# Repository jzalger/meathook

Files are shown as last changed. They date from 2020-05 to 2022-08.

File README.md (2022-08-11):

# Meat Hook







Meat Hook is a temperature and humidity controlled fridge for dry aging meat.
This project goes through designing the circuit and PCB as well as the surrounding full-stack web application and data
logging utilities. It also explores using various control algorithms including basic, PID, and machine learning approaches.

The controller is based on the [Particle Photon](http://www.particle.io), a Wifi enabled ARM based processor with a cloud-based API.
The web application backend is written in Python using the Flask framework. The frontend uses HTML and Javascript, leveraging the Bootstrap framework.

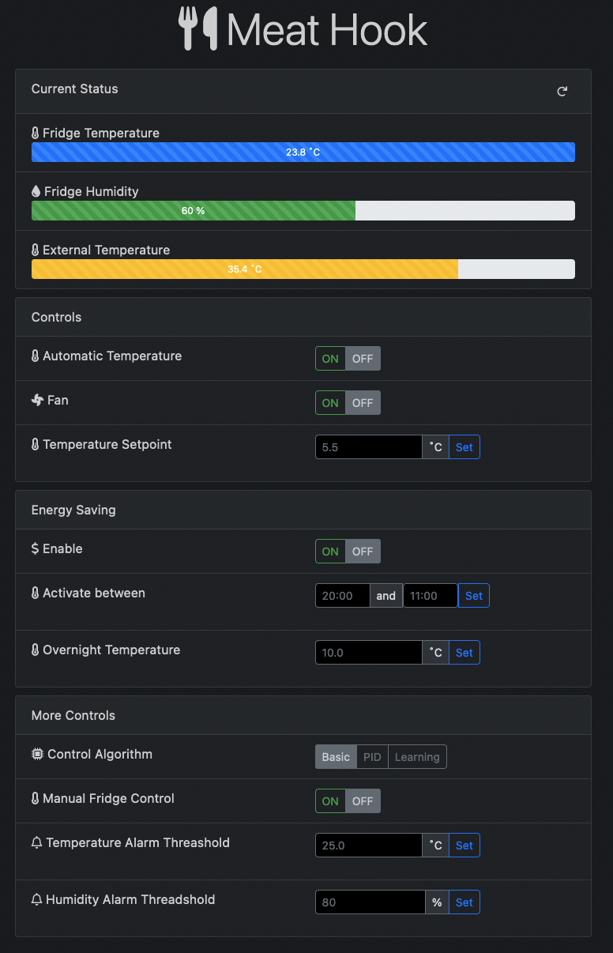
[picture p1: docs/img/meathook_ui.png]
User Interface


## Circuit and PCB Design

Below is a simple block diagram showing the sensors and actuators in the fridge.

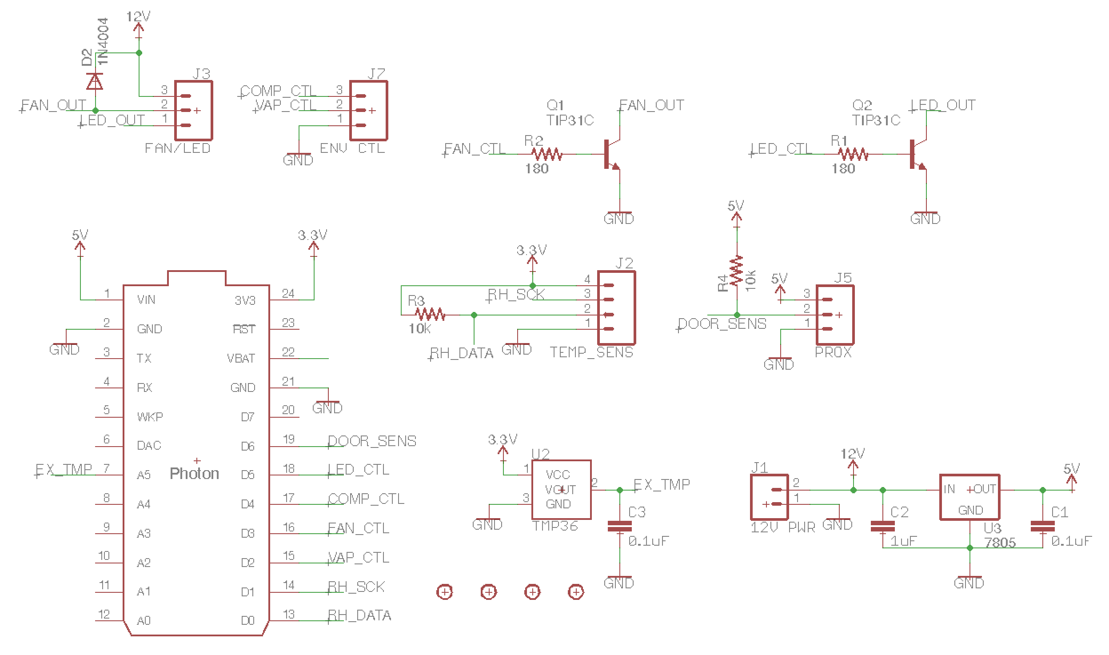
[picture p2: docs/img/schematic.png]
Schematic


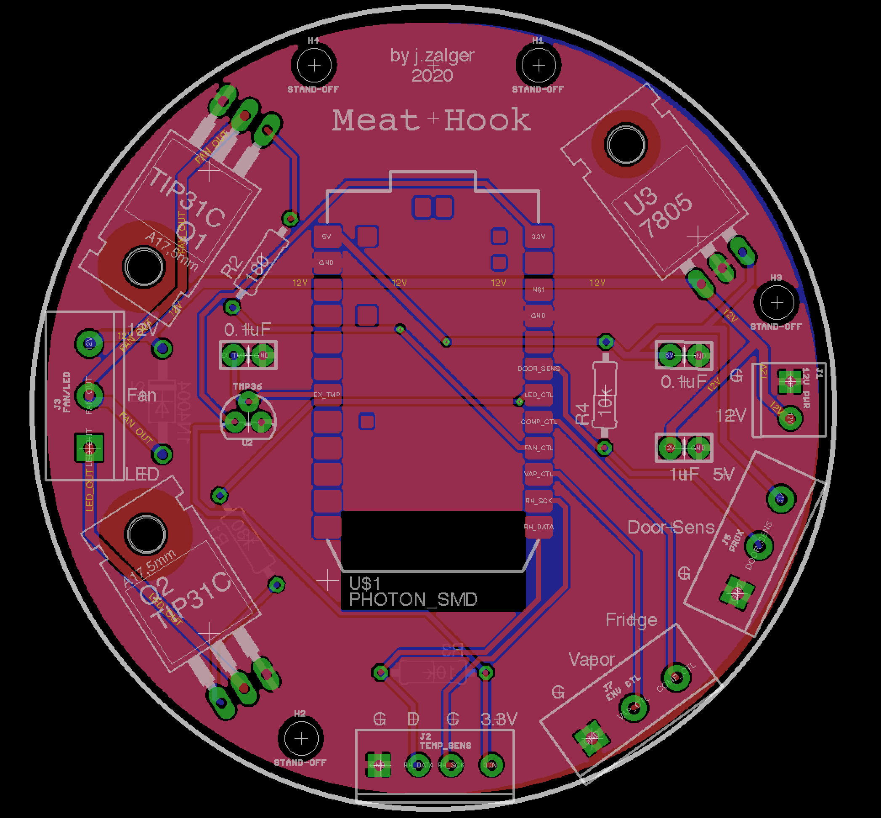
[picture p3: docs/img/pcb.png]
PCB


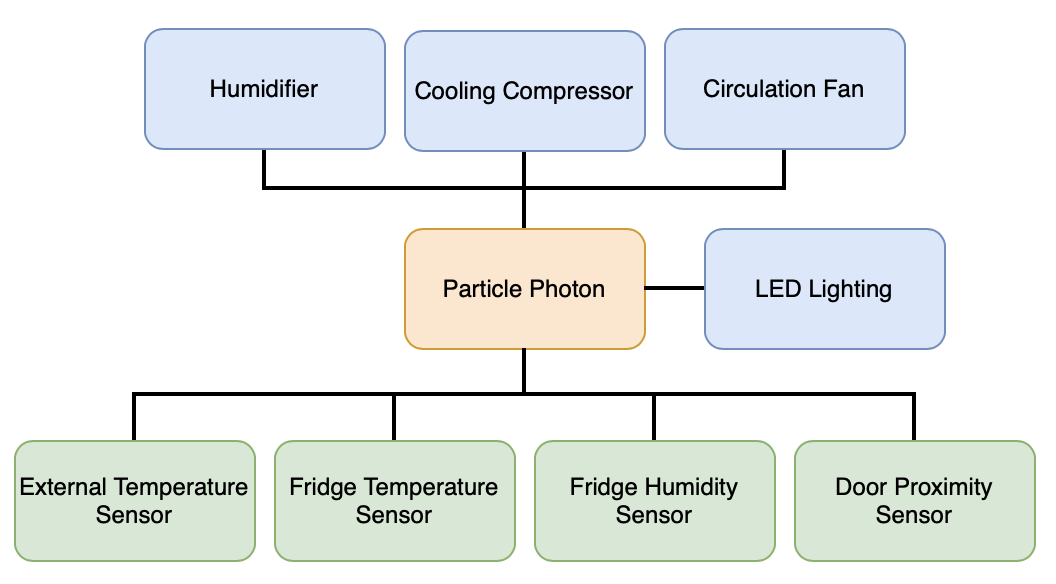
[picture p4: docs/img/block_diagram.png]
Block Diagram


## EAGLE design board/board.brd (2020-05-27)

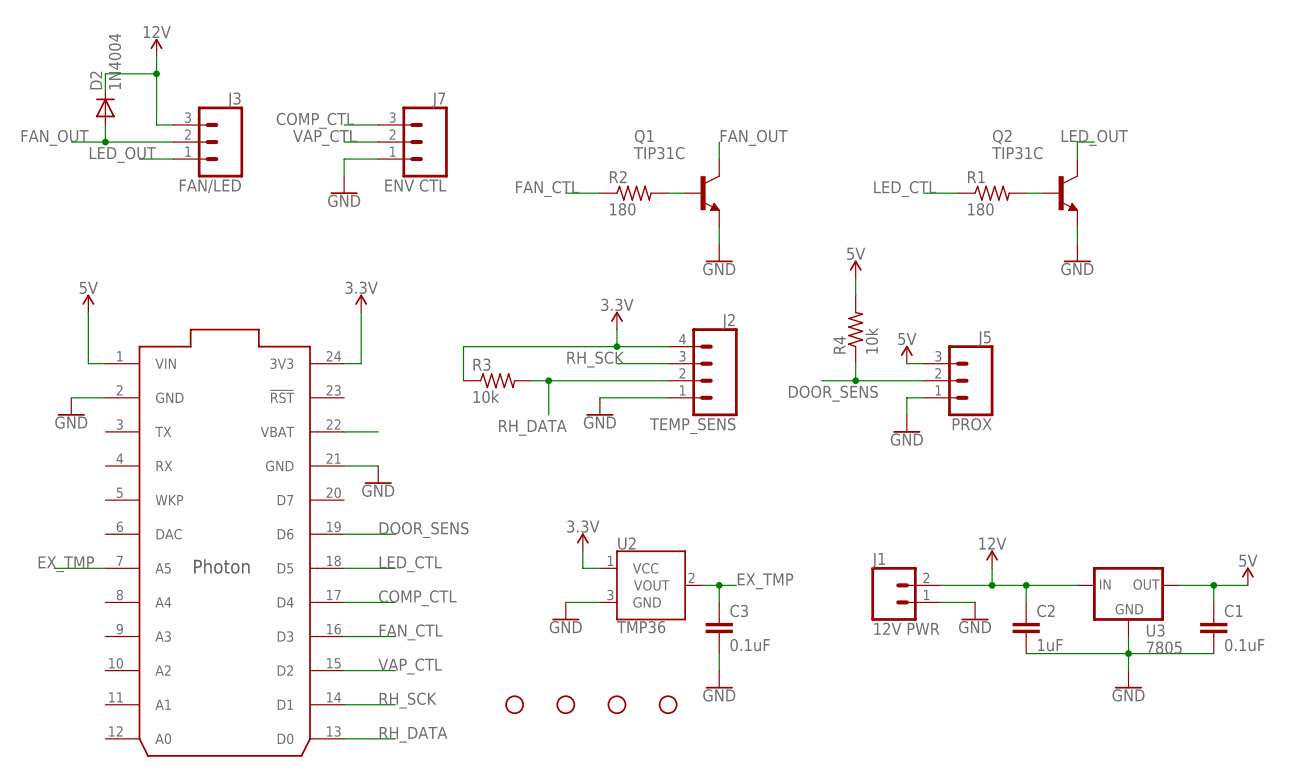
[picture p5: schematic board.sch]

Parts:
C1, C3: 0.1uF; CAP-PTH-SMALL-KIT
C2: 1uF; CAP-PTH-SMALL-KIT
D2: 1N4004; DO41-10
H1, H2, H3, H4: STAND-OFF
J1: 12V PWR; SCREWTERMINAL-3.5MM-2
J2: TEMP_SENS; SCREWTERMINAL-3.5MM-4_LOCK
J3: FAN/LED; SCREWTERMINAL-5MM-3
J5: PROX; SCREWTERMINAL-5MM-3
J7: ENV CTL; SCREWTERMINAL-5MM-3
Q1, Q2: TIP31C; TO220
R1, R2: 180; 0207/10
R3, R4: 10k; 0207/10
U2: TMP36; TO-92
U3: 7805; TO-220-ALT
U$1: PHOTON_SMD

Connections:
3.3V: J2.4, R3.1, U2.1 (VCC), U$1.24 (3V3)
5V: C1.1, J5.3, R4.2, U3.OUT, U$1.1 (VIN)
12V: C2.1, D2.C, J1.2, J3.3, U3.IN
COMP_CTL: J7.3, U$1.17 (D4)
DOOR_SENS: J5.2, R4.1, U$1.19 (D6)
EX_TMP: C3.1, U2.2 (VOUT), U$1.7 (A5)
FAN_CTL: R2.1, U$1.16 (D3)
FAN_OUT: D2.A, J3.2, Q1.2 (C)
GND: C1.2, C2.2, C3.2, J1.1, J2.1, J5.1, J7.1, Q1.3 (E), Q2.3 (E), U2.3 (GND), U3.GND, U$1.2 (GND), U$1.21 (GND)
LED_CTL: R1.1, U$1.18 (D5)
LED_OUT: J3.1, Q2.2 (C)
unnamed: Q2.1 (B), R1.2
unnamed: Q1.1 (B), R2.2
RH_DATA: J2.2, R3.2, U$1.13 (D0)
RH_SCK: J2.3, U$1.14 (D1)
VAP_CTL: J7.2, U$1.15 (D2)

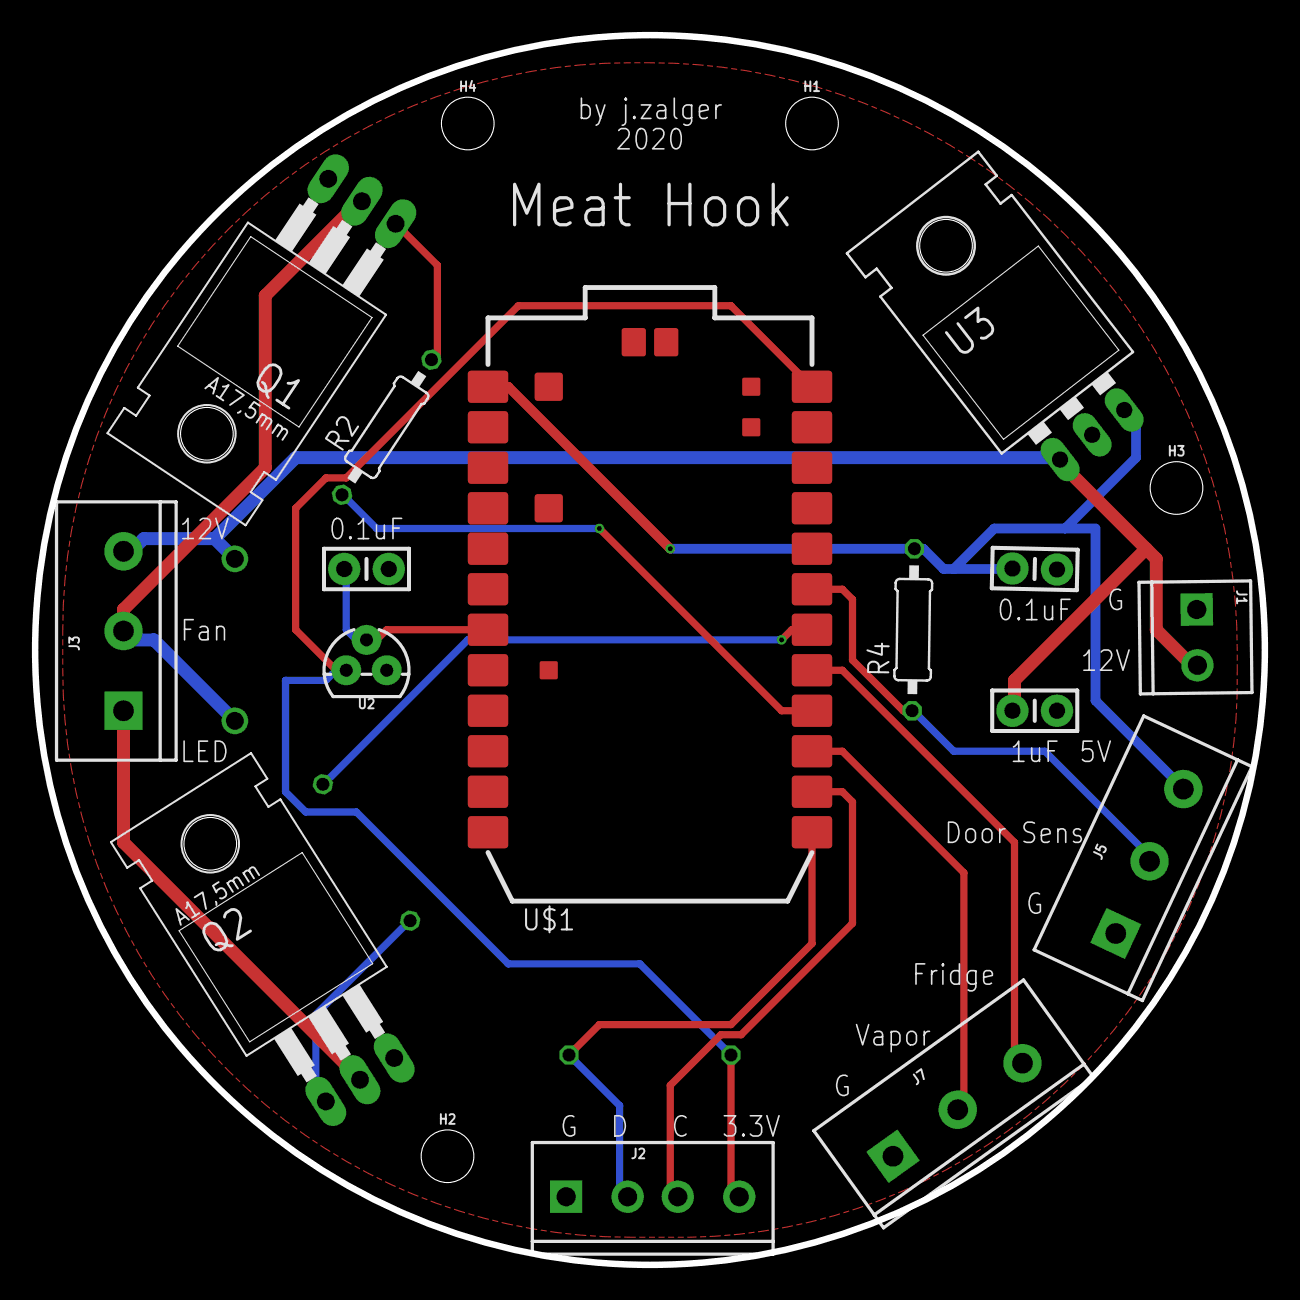
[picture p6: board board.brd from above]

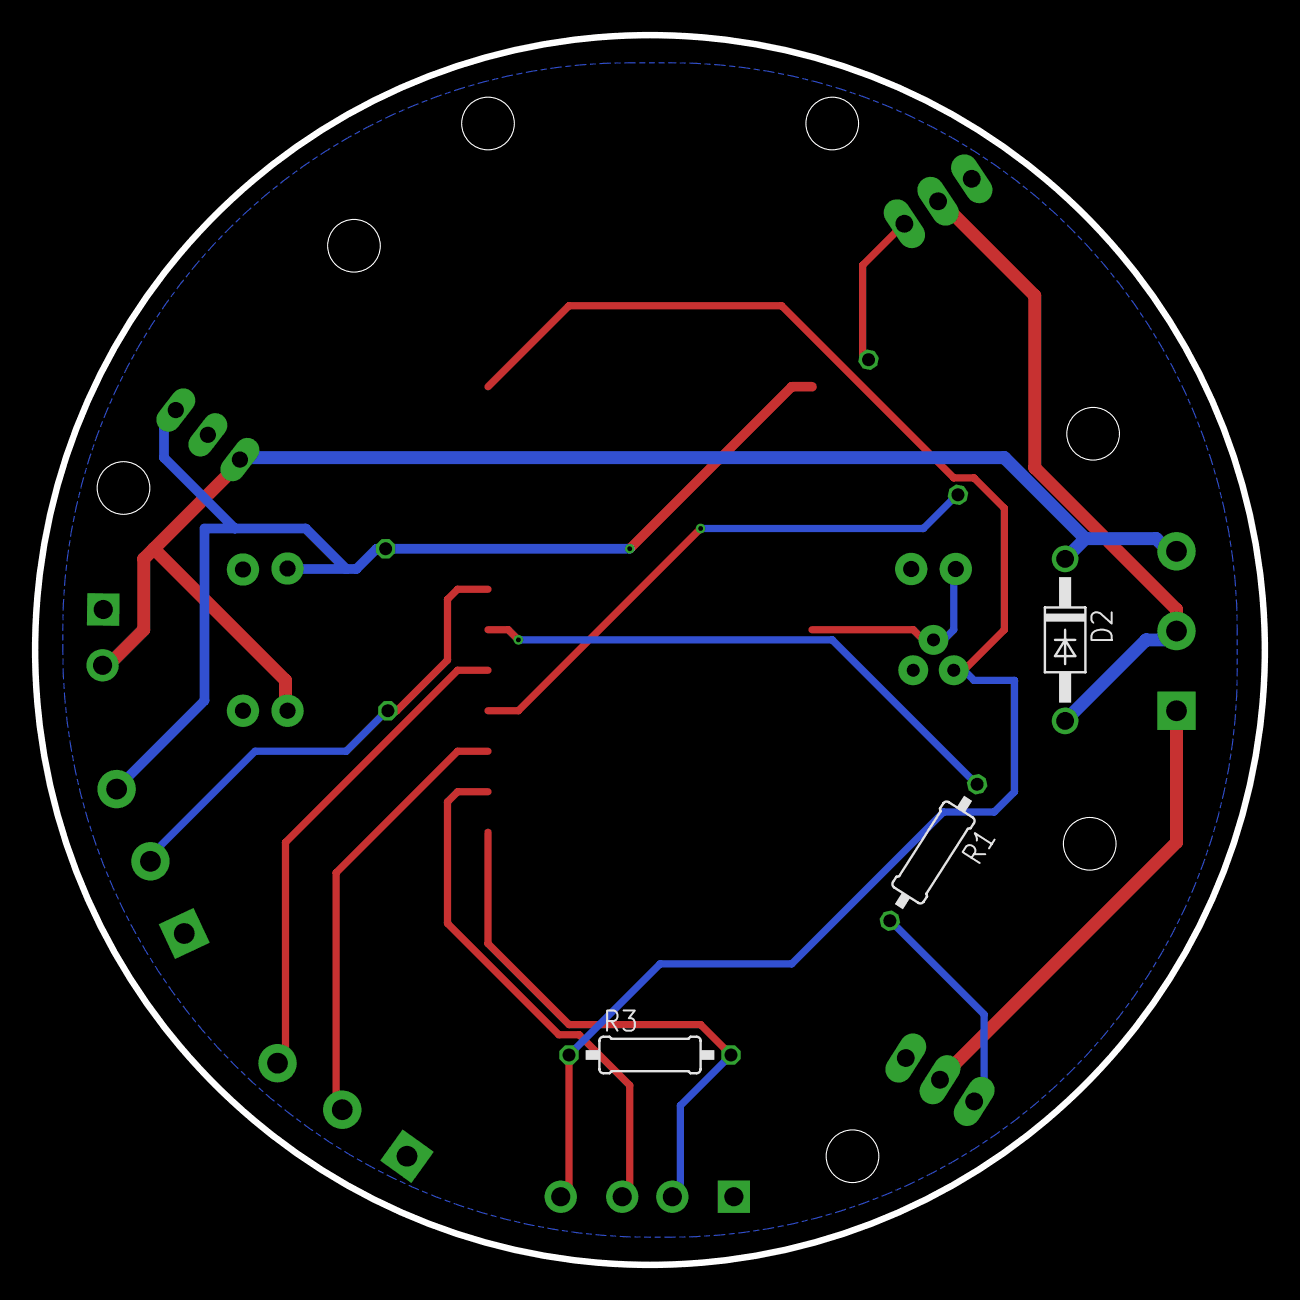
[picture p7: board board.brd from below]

Board: 2 copper layers, 77.1 x 77.1 mm, 22 parts (3 on the bottom side), 16 nets.

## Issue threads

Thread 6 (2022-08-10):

Persist state to device flash and recover to it on reboot

jzalger, 2022-08-10:

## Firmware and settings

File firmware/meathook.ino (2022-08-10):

// MeatHook
// J. Zalger - 2022
SYSTEM_THREAD(ENABLED);
#include <SHT1x.h>
#include <pid.h>
#include <string>
#include "basic_control.h"

#define REF_VOLTAGE 3.4  //Voltage reference for external temp sensor
#define SHT_SCK D1
#define SHT_DATA D0
#define FAN_PIN D3
#define FRIDGE_PIN D4
#define LED_PIN D5
#define DOOR_SENS D6
#define EXT_TEMP_PIN A5

double external_temp = 0.0;
double fridge_temp = 0.0;
double fridge_rh = 0.0;

// Parameters for PID control
double temp_setpoint = 5.5;
double current_temp_setpoint = temp_setpoint;
double es_temp_setpoint = temp_setpoint;
double temp_pid_output = 0.0;
int pid_temp_window_size = 60000;   // Time in milliseconds
unsigned long pid_temp_window_start_time;

int compressor_protect_time = 300;  // Time in seconds
int last_fridge_action = -compressor_protect_time * 1000;

double temp_alarm_delta = 15.0;  //+- deg C from setpoint to trigger alarm
double rh_alarm_limit = 50.0;    //Upper Rh limit to trigger alarm

bool temp_control = TRUE;
bool fan_state = TRUE;
bool fridge_state = FALSE;
bool temp_alarm = FALSE;
bool rh_alarm = FALSE;
bool stream_data = TRUE;
bool door_state = FALSE;  // False = CLOSED
bool logging_mode = TRUE;
bool led_state = FALSE;
bool es_state = FALSE;

struct ESTime {
    int hour = 0;  //Hours in 24 hr time 0-23
    int minutes = 0;  // Minutes in hour 0-59
    };

String es_start_string = "22:00";
String es_stop_string = "10:00";
ESTime es_start_time;
ESTime es_stop_time;

String state = "";

int stream_interval = 1; // Stream update interval in minutes
unsigned long last_stream_update;
unsigned long last_alarm_message;

SHT1x fridge_sensor(SHT_DATA, SHT_SCK);

String control_algorithm = "basic";

// Note: These PID settings here are arbitrary
PID temp_pid(&fridge_temp, &temp_pid_output, &current_temp_setpoint, 2.0, 2.0, 1.0, PID::P_ON_M, PID::DIRECT);

// Basic Control for temperature
BasicControl basic_temp_control(&fridge_temp, &current_temp_setpoint);

void setup() {
    pinMode(FRIDGE_PIN, OUTPUT);
    pinMode(FAN_PIN, OUTPUT);
    pinMode(LED_PIN, OUTPUT);

    Particle.variable("fridge_state", fridge_state);
    Particle.variable("external_temp", external_temp);
    Particle.variable("fridge_temp", fridge_temp);
    Particle.variable("fridge_rh", fridge_rh);
    Particle.variable("temp_setpoint", temp_setpoint);
    Particle.variable("current_temp_setpoint", current_temp_setpoint);
    Particle.variable("temp_control", temp_control);
    Particle.variable("fan_state", fan_state);
    Particle.variable("temp_alarm", temp_alarm);
    Particle.variable("rh_alarm", rh_alarm);
    Particle.variable("temp_alarm_delta", temp_alarm_delta);
    Particle.variable("rh_alarm_limit", rh_alarm_limit);
    Particle.variable("control_algorithm", control_algorithm);
    Particle.variable("led_state", led_state);
    Particle.variable("door_state", door_state);
    Particle.variable("es_state", es_state);
    Particle.variable("es_temp_setpoint", es_temp_setpoint);
    Particle.variable("es_start", es_start_string);
    Particle.variable("es_stop", es_stop_string);

    Particle.function("set_temp_setpoint", set_temp_setpoint);
    Particle.function("set_control", set_control);
    Particle.function("set_temp_control", set_temp_control);
    Particle.function("set_stream_data", set_stream_data);
    Particle.function("set_stream_interval", set_stream_interval);
    Particle.function("set_temp_alarm_delta", set_temp_alarm_delta);
    Particle.function("set_rh_alarm_limit", set_rh_alarm_limit);
    Particle.function("set_fan_state", set_fan_state);
    Particle.function("set_fridge_state", set_fridge_state);
    Particle.function("set_control_algorithm", set_control_algorithm);
    Particle.function("set_led_state", set_led_state);
    Particle.function("es_state", set_es_state);
    Particle.function("es_temp_setpoint", set_es_temp_setpoint);
    Particle.function("es_start", set_es_start_string);
    Particle.function("es_stop", set_es_stop_string);

    if (control_algorithm == "pid"){
        temp_pid.SetOutputLimits(0, pid_temp_window_size);
        temp_pid.SetMode(PID::AUTOMATIC);
    }
}

void loop() {
    delay(1000); // Dont overdrive the system

    // Turn on lights if door opens
    manage_light();

    external_temp = (((analogRead(EXT_TEMP_PIN) * REF_VOLTAGE) / 4095.0) - 0.5) * 100;
    fridge_temp = fridge_sensor.readTemperatureC();
    fridge_rh = fridge_sensor.readHumidity();

    // Account for energy saving
    if (es_state == TRUE){
        if (Time.hour() <= es_start_time.hour && Time.minute() <= es_start_time.minutes &&
            Time.hour() >= es_stop_time.hour && Time.minute() >= es_stop_time.minutes) {
                //Outside the ES Window
                current_temp_setpoint = temp_setpoint;
        } else {
            current_temp_setpoint = es_temp_setpoint;
        }
    } else {
        current_temp_setpoint = temp_setpoint;
    }

    if (temp_control == TRUE) {
        adjust_control();
    }

    if (fan_state == TRUE) {
        start_fan();
    } else {
        stop_fan();
    }

    handle_alarms();

    // Post readings to the cloud server
    if (stream_data == TRUE) {
        if ((millis() - last_stream_update) / 1000 > (stream_interval * 60)) {
            publish_state();
        }
    }
}


//##########################################################################################

void adjust_control(){
    if (control_algorithm == "pid"){
        temp_pid.Compute();
        unsigned long now = millis();
        if (now - pid_temp_window_start_time > pid_temp_window_size) {
            pid_temp_window_start_time += pid_temp_window_size;
        }
        if (temp_pid_output > now - pid_temp_window_start_time){
            start_fridge();
        } else {
            stop_fridge();
        }

    } else if (control_algorithm == "basic"){
        bool action = basic_temp_control.compute_action();
        if (action == TRUE){
            start_fridge();
        } else {
            stop_fridge();
        }
    }
}

void handle_alarms(){
    if (fridge_temp > temp_setpoint + temp_alarm_delta ||
            fridge_temp < temp_setpoint - temp_alarm_delta) {
                temp_alarm = TRUE;
    } else {
        temp_alarm = FALSE;
    }
    if (fridge_rh > rh_alarm_limit) {
        rh_alarm = TRUE;
    } else {
        rh_alarm = FALSE;
    }
}

void publish_state() {
    state = "fridge_temp=" + String(fridge_temp) + "," +
            "fridge_rh=" + String(fridge_rh) + "," +
            "external_temp=" + String(external_temp) + "," +
            "fridge_state=" + String::format("%s", fridge_state ? "True" : "False")  + "," +
            "fan_state=" + String::format("%s", fan_state ? "True" : "False") + "," +
            "door_state=" + String::format("%s", door_state ? "True" : "False") + "," +
            "temp_setpoint=" + String(temp_setpoint) + "," +
            "temp_alarm=" + String::format("%s", temp_alarm ? "True" : "False") + "," +
            "rh_alarm=" + String::format("%s", rh_alarm ? "True" : "False") + "," +
            "control_algorithm=" + control_algorithm + "," +
            "temp_alarm_delta=" + String(temp_alarm_delta) + "," +
            "rh_alarm_limit=" + String(rh_alarm_limit) + "," +
            "temp_control=" + String(temp_control ? "True" : "False") + "," +
            "es_state=" + String::format("%s", es_state ? "True" : "False") + "," +
            "es_temp_setpoint=" + String(es_temp_setpoint) + "," +
            "es_start=" + String(es_start_string) + "," +
            "es_stop=" + String(es_stop_string) + "," +
            "current_temp_setpoint=" + String(current_temp_setpoint);

    Particle.publish("state", state);
    last_stream_update = millis();
}

void start_fridge(){
    int time_since_last_action = millis() - last_fridge_action;
    if (time_since_last_action >= compressor_protect_time * 1000){
        digitalWrite(FRIDGE_PIN, HIGH);
        fridge_state = TRUE;
    }
}

void stop_fridge(){
    digitalWrite(FRIDGE_PIN, LOW);
    if (fridge_state == TRUE) {
        last_fridge_action = millis();
    }
    fridge_state = FALSE;
}


void start_fan(){
    digitalWrite(FAN_PIN, HIGH);
    fan_state = TRUE;
}

void stop_fan(){
    digitalWrite(FAN_PIN, LOW);
    fan_state = FALSE;
}

void manage_light(){
    door_state = digitalRead(DOOR_SENS);
    if (door_state == TRUE or led_state == TRUE){
        digitalWrite(LED_PIN, HIGH);
    } else {
        digitalWrite(LED_PIN, LOW);
    }
}

int set_temp_setpoint(String arg){
    temp_setpoint = arg.toFloat();
    return 0;
}

int set_control(String arg){
    if (arg == "ON") {
        temp_control = TRUE;
        return 0;
    } else if (arg == "OFF"){
        temp_control = FALSE;
        return 0;
    } else {
        return -1;
    }
}
int set_temp_control(String arg){
    if (arg == "ON") {
        temp_control = TRUE;
        return 0;
    } else if (arg == "OFF"){
        temp_control = FALSE;
        return 0;
    } else {
        return -1;
    }
}

int set_fridge_state(String arg){
    if (arg == "ON") {
        start_fridge();
        return 0;
    } else if (arg == "OFF"){
        stop_fridge();
        return 0;
    } else {
        return -1;
    }
}

int set_stream_data(String arg){
    if (arg == "ON"){
        stream_data = TRUE;
        return 0;
    } else if (arg == "OFF"){
        stream_data = FALSE;
        return 0;
    } else {
        return -1;
    }
}
int set_stream_interval(String arg){
    stream_interval = arg.toInt();
    return 0;
}
int set_temp_alarm_delta(String arg){
    temp_alarm_delta = arg.toFloat();
    return 0;
}
int set_rh_alarm_limit(String arg){
    rh_alarm_limit = arg.toFloat();
    return 0;
}
int set_fan_state(String arg){
    if (arg == "ON") {
        start_fan();
        return 0;
    } else if (arg == "OFF") {
        stop_fan();
        return 0;
    } else {
        return -1;
    }
}
int set_led_state(String arg){
    if (arg == "ON") {
        led_state = TRUE;
        return 0;
    } else if (arg == "OFF") {
        led_state = FALSE;
        return 0;
    } else {
        return -1;
    }
}
int set_control_algorithm(String arg){
    if (arg == "basic"){
        control_algorithm = "basic";
        return 0;
    } else if (arg == "pid") {
        control_algorithm = "pid";
        return 0;
    } else {
        return -1;
    }
}
int set_es_state(String arg){
    if (arg == "ON") {
        es_state = TRUE;
        return 0;
    } else if (arg == "OFF"){
        es_state = FALSE;
        return 0;
    } else {
        return -1;
    }
}
int set_es_temp_setpoint(String arg){
    temp_setpoint = arg.toFloat();
    return 0;
}
int set_es_start_string(String arg){
    es_start_string = arg;
    es_start_time.hour = es_start_string.substring(0,0).toInt();
    es_start_time.minutes = es_start_string.substring(3).toInt();
    return 0;
}
int set_es_stop_string(String arg){
    es_stop_string = arg;
    es_stop_time.hour = es_start_string.substring(0,0).toInt();
    es_stop_time.minutes = es_start_string.substring(3).toInt();
    return 0;
}

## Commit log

2020-05-22 Added board, schematic, and gerbers
    [board.brd, board.sch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]
2020-05-22 Added pcb and schematic images
2020-05-23 - Added device control class - Backend updates.
2020-05-24 - control wiring
2020-05-26 - various bug fixes and firmware updates - alarm UI not working well. need to subscribe to the alarm event feeds and make the returned values consistent. Check the js alarm parsing as well.
    [meathook.ino]
2020-11-21 - Implemented live stream backend with LED control
2022-08-10 Added sonarcube properties
2022-08-10 Added force state refresh button

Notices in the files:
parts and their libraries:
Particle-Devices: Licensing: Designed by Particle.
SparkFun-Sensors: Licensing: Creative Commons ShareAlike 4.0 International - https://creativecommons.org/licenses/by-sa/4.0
